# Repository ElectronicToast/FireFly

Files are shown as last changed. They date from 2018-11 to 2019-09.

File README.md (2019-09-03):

# FireFly

 

Open source ATmega8 target board with voltage regulation and ICSP, FTDI breakouts.

&nbsp;

FireFly

## Description

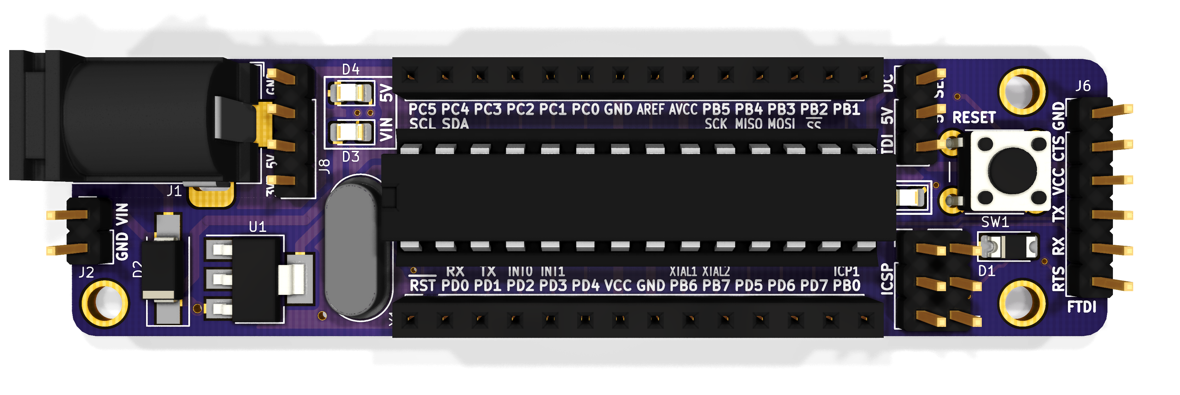
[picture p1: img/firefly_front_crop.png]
FireFly-Front


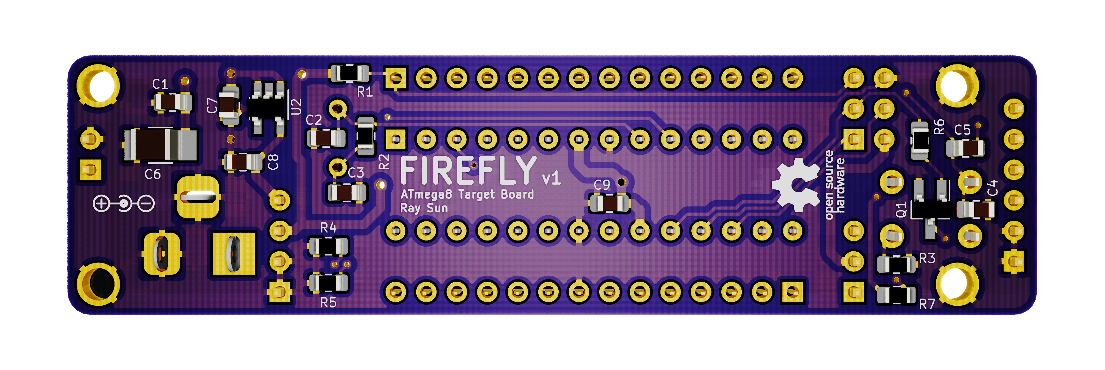
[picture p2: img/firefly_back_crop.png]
FireFly-Back


FIREFLY is an open-source ATmega8 (ATmega328) target board that might be likened to a lightweight yet accessible Arduino Uno R3. It is intended to be used for learning AVR C/C++ or AVR Assembly with Atmel Studio. A 16 MHz oscillator and reset circuit is provided for a complete microcontroller system. 5V and 3V3 power are created from DC input. The 28 pins of the ATmega8 DIP package are brought out onto breadboard-compatible headers so that the whole board may be plugged directly into a breadboard and used.

The ATmega8 may be programmed through the onboard ICSP or FTDI headers with an appropriate programmer. The power source for the target may be selected by a jumper shunt; when programming, take care not to power the target through the DC input (VIN) in addition to the programmer.

Designed with KiCad EDA 5.0.1. Gerber and drill files for fabrication may be found in `/gerber`, while documentation in pdf format may be found in `/pdf`. 

## Author
- Ray Sun - Undergraduate, Electrical Engineering, Caltech, Class of 2020

I created this board to help me enhance my knowledge of embedded systems development and working with AVRs.

## Licensing
<br />This work is licensed under a <a rel="license" href="http://creativecommons.org/licenses/by-sa/3.0/">Creative Commons Attribution-ShareAlike 3.0 Unported License</a>.

This design is a derivative of the [Arduino Uno Rev3](https://store.arduino.cc/usa/arduino-uno-rev3) board and is inspired by Adafruit Industries' [DC Boarduino](https://www.adafruit.com/product/72) by Limor Fried. Arduino is a trademark of Arduino AG. This design is not affiliated with Arduino AG.

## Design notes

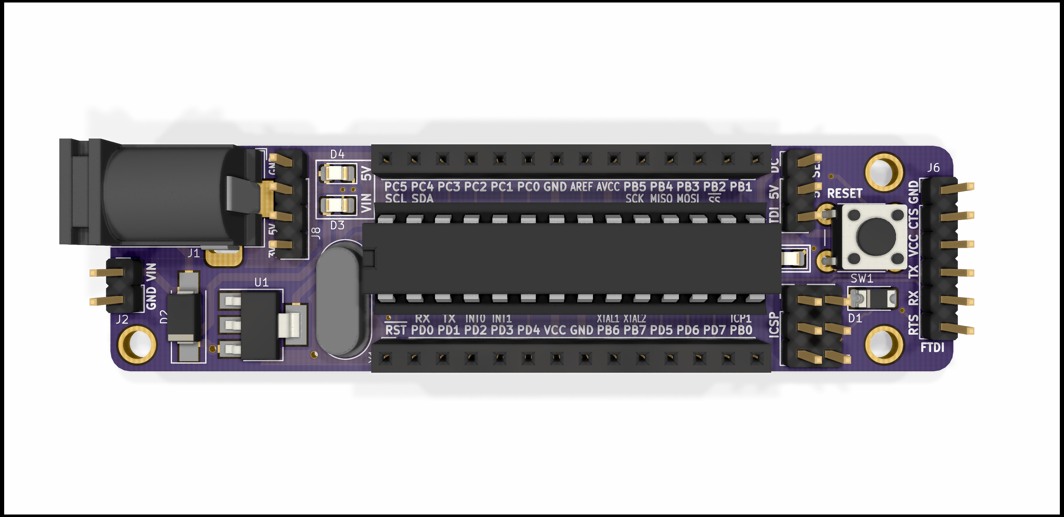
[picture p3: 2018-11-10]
img/firefly_front.png

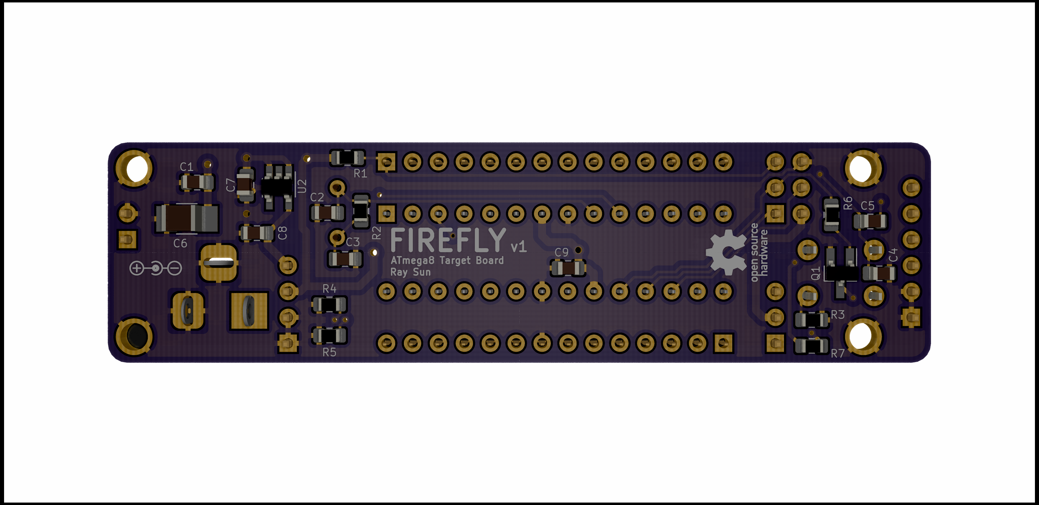
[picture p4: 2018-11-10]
img/firefly_back.png

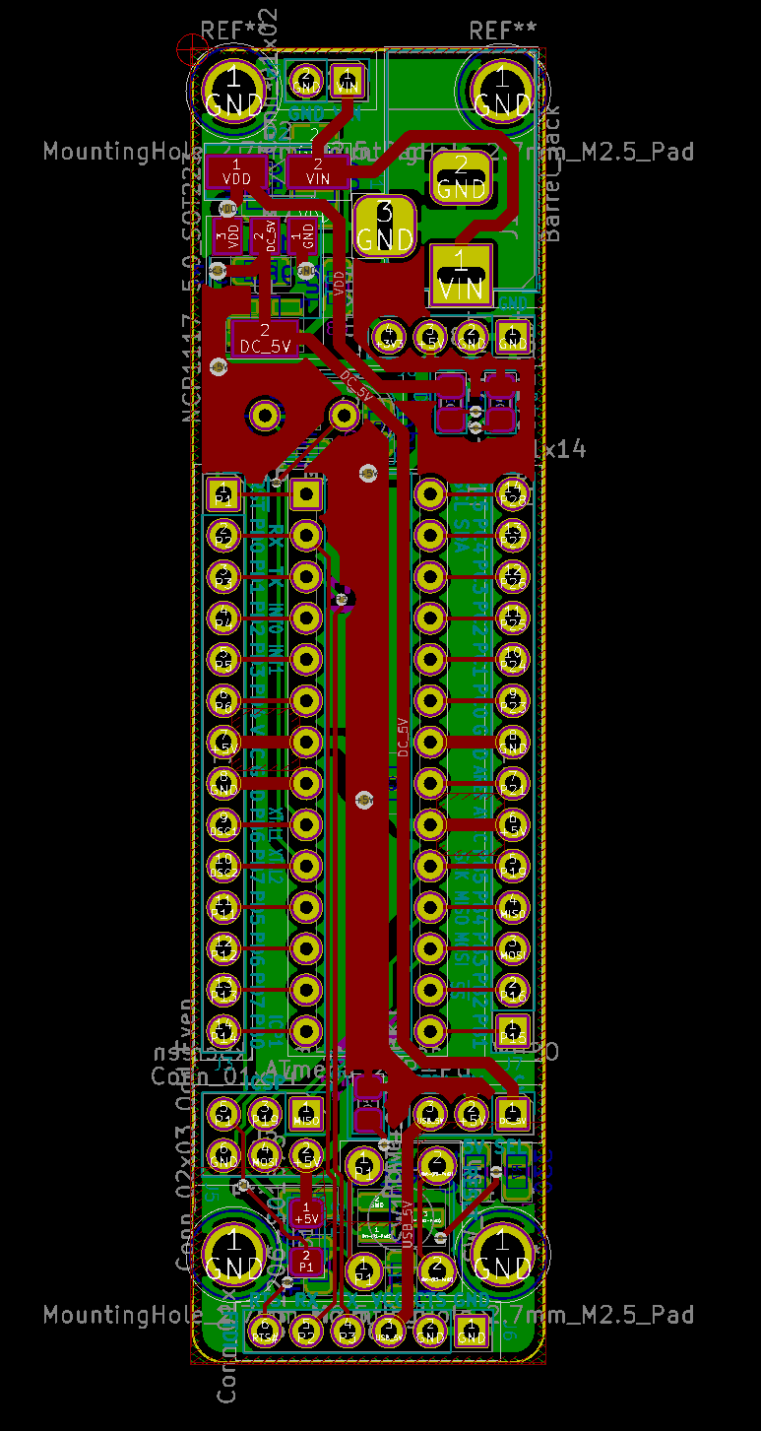
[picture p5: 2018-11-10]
img/firefly_layout.PNG

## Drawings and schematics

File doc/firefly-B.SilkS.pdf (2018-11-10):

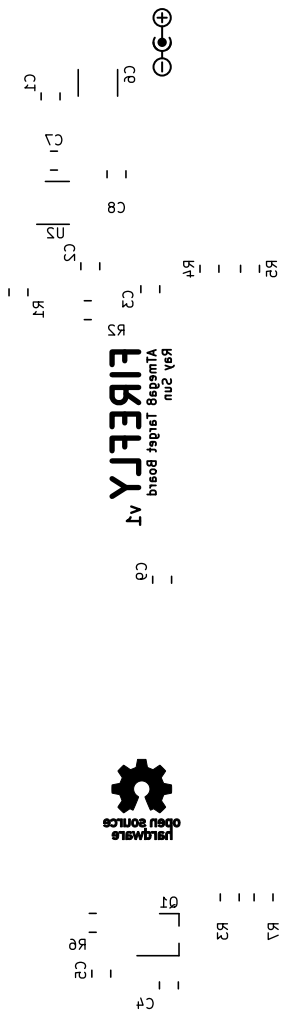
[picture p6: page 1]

v1 FIREFLY ATmega8 Target Board Ray Sun C9 C1 C7 C8 C2 C3 C5 C4 R2 R1 R4 R5 R3 R7 U2 C6 Q1 R6

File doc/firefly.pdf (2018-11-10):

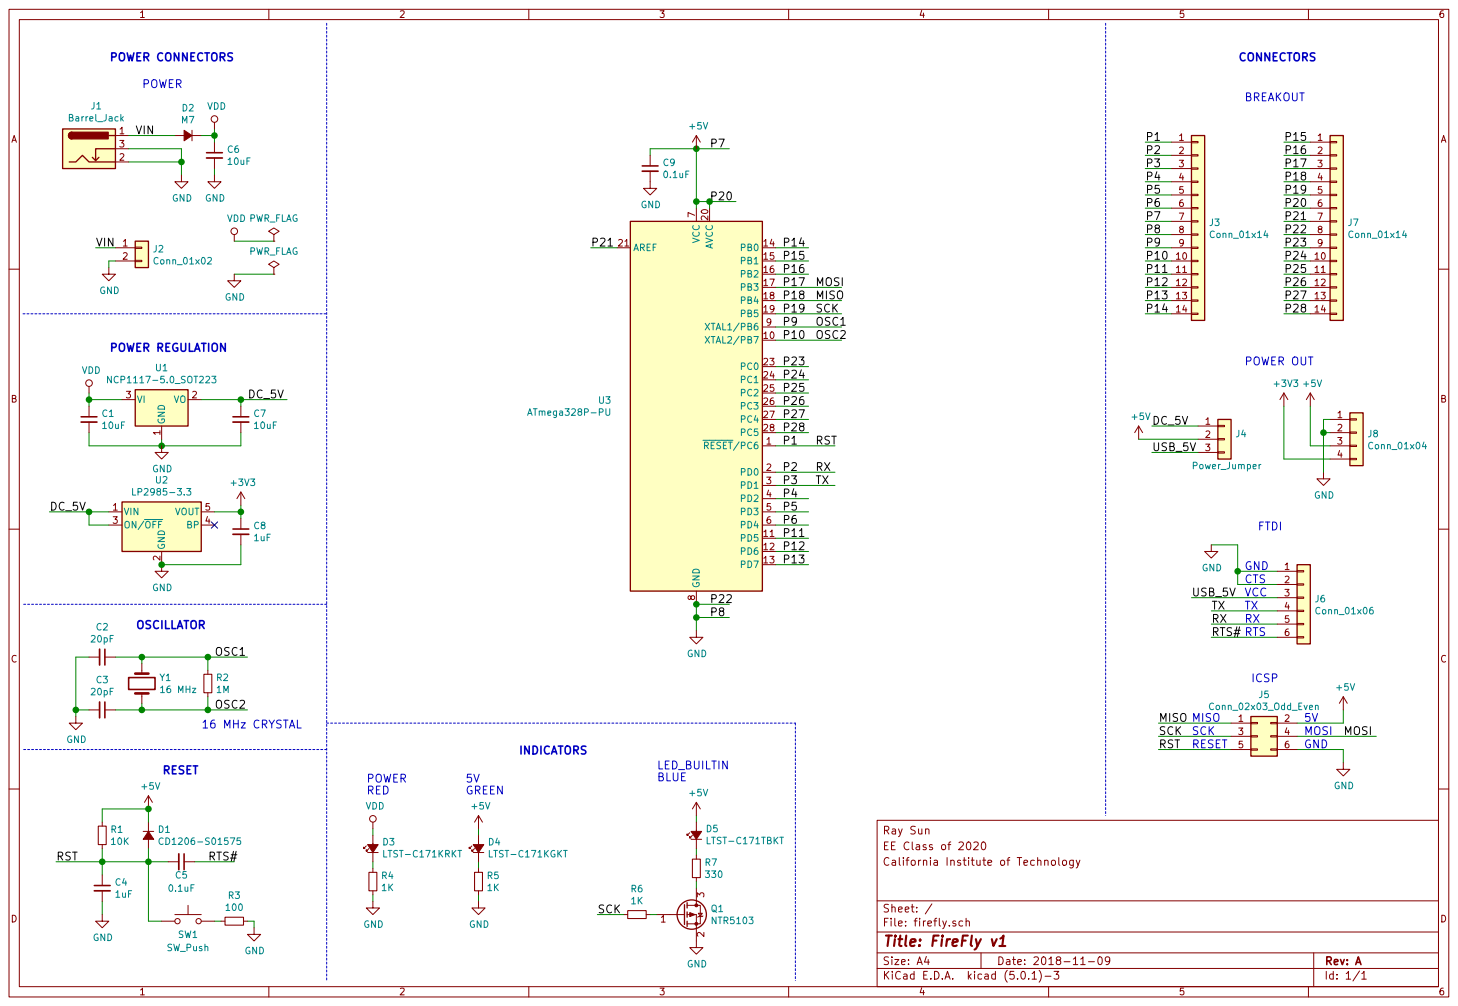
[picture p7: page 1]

1 VO 2 VI 3 U1 NCP1117-5.0_SOT223 VIN 1 GND
VDD

File: firefly.sch Sheet: / California Institute of Technology EE Class of 2020 Ray Sun

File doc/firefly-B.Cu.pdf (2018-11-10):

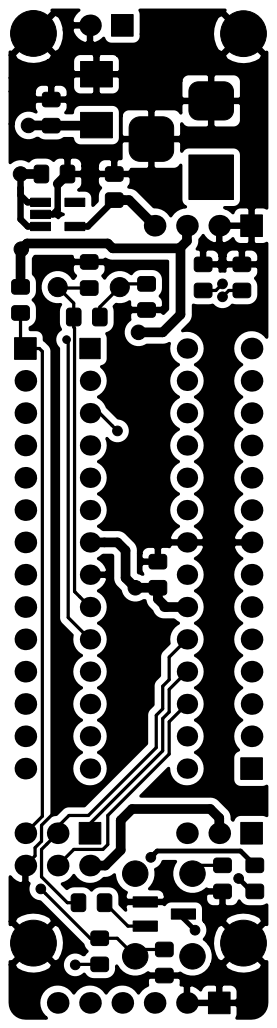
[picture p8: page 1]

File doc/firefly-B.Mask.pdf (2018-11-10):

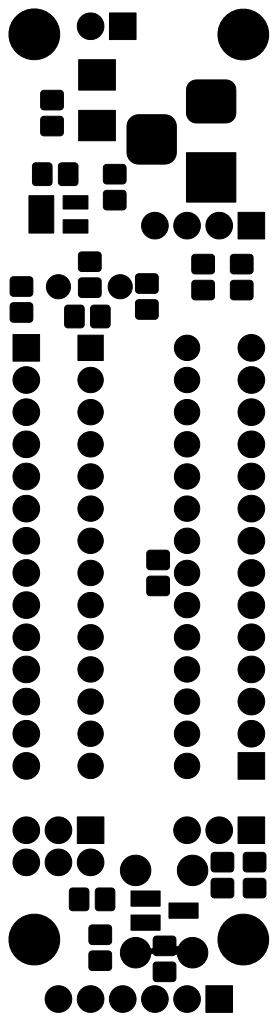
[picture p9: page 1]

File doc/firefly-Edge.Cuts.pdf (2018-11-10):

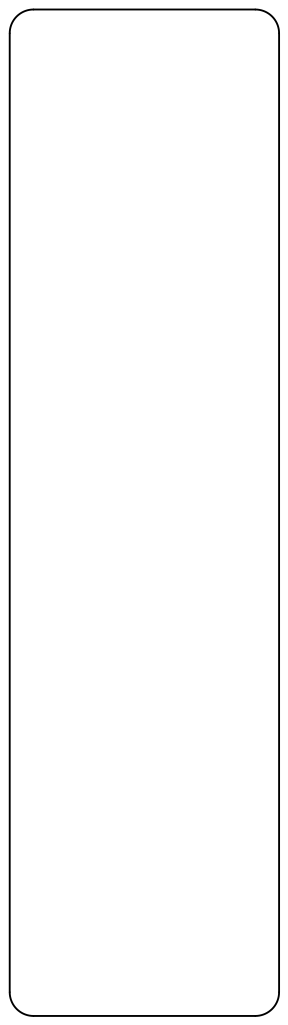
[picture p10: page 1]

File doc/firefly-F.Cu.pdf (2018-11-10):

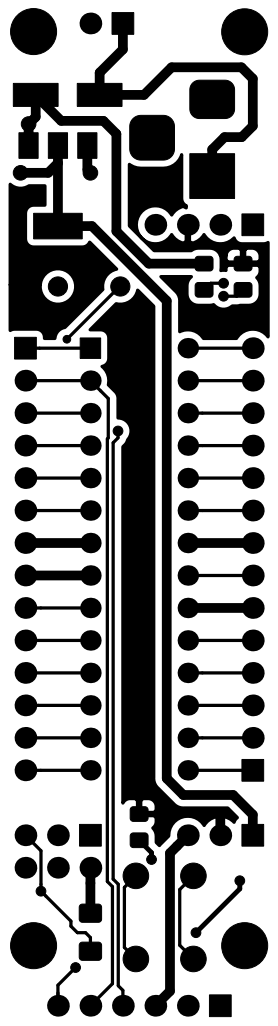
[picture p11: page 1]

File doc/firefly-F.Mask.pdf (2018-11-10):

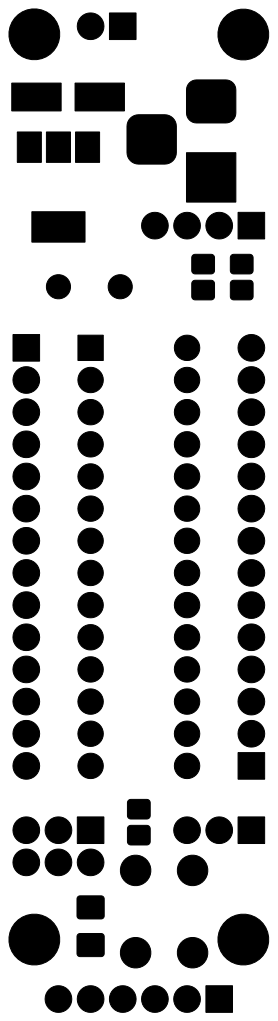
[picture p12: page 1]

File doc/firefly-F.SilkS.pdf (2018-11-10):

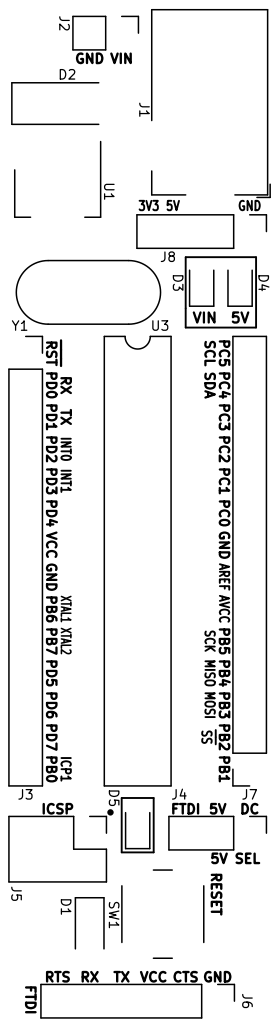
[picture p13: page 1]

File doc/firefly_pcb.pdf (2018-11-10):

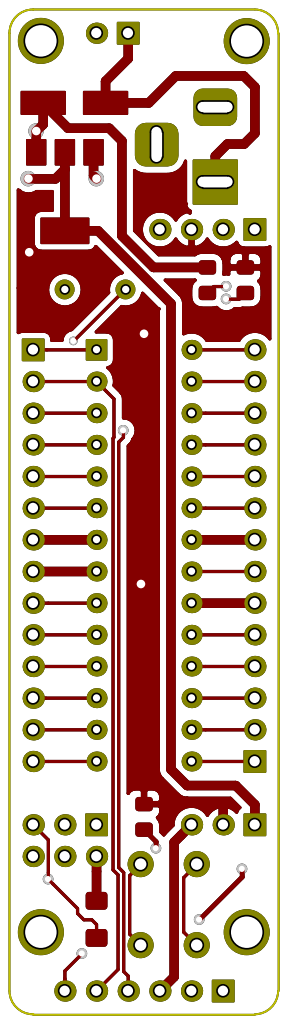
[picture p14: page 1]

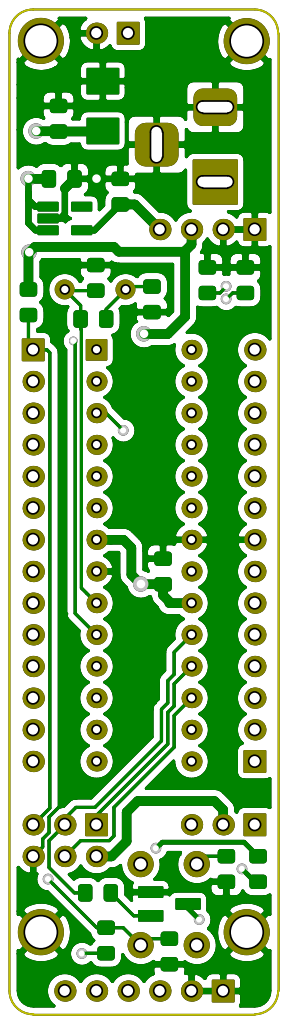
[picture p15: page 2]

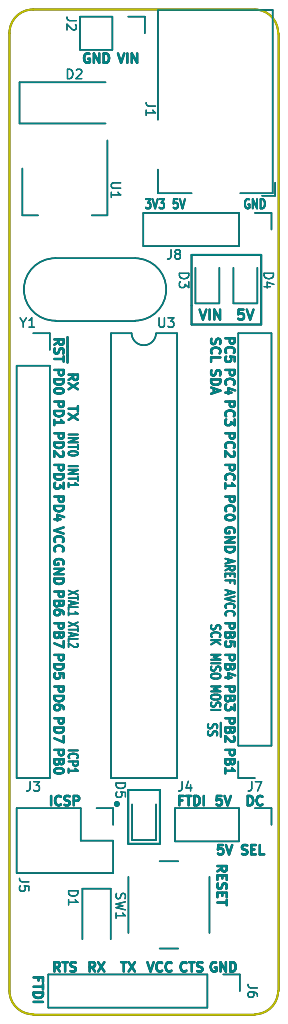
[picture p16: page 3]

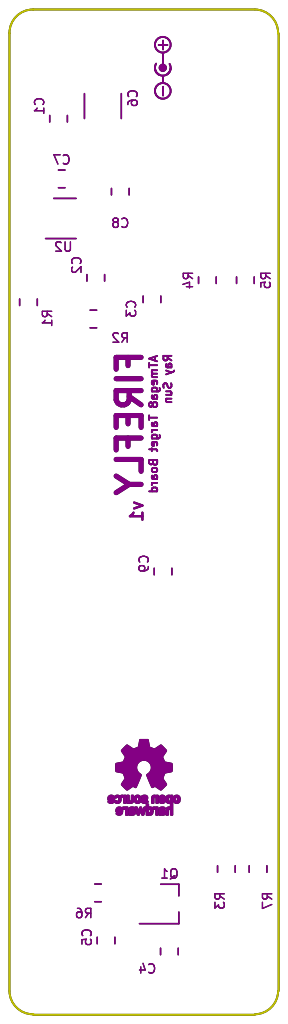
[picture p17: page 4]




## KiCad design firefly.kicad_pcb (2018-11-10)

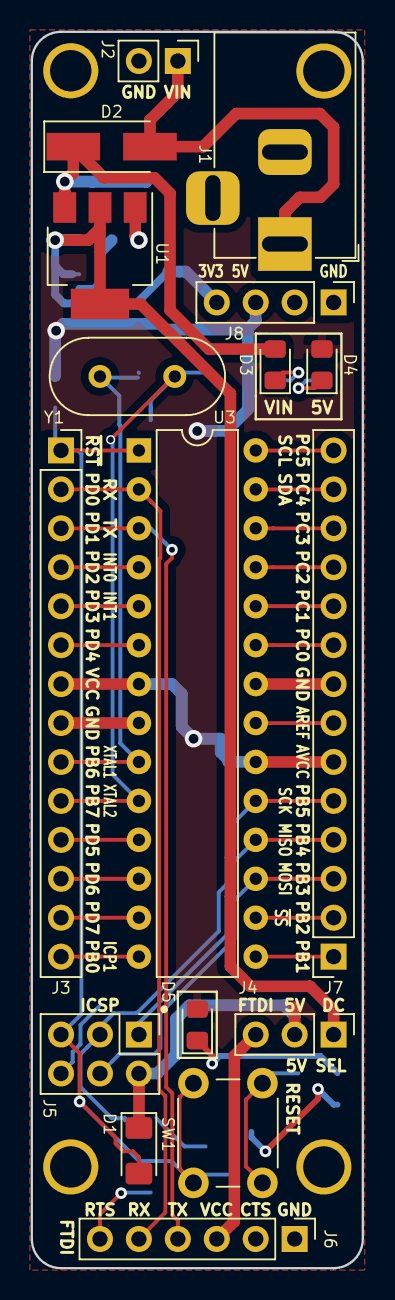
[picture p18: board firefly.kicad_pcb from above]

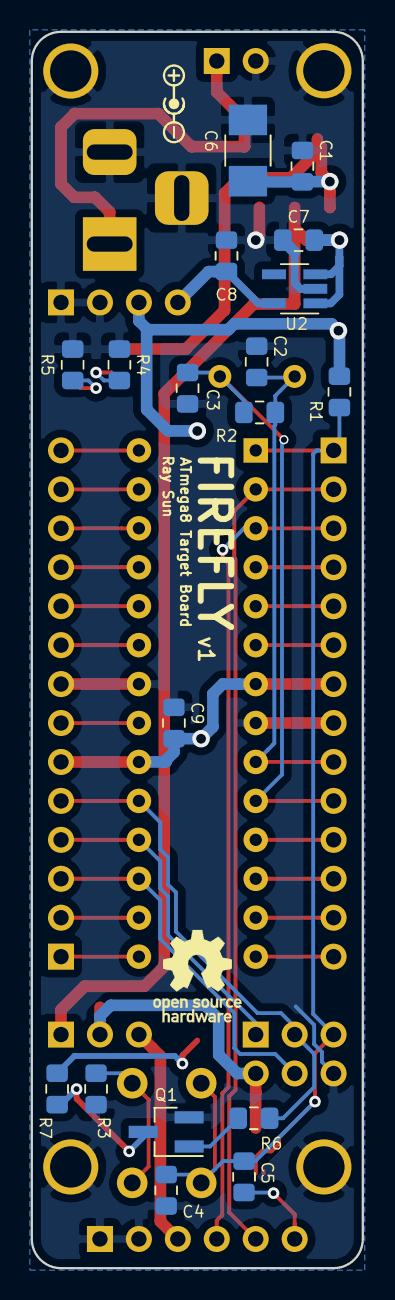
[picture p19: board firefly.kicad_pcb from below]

Board: 2 copper layers, 21.6 x 80.6 mm, 35 parts (18 on the bottom side), 38 nets.

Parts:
C1, C7: 10uF; C_0805_2012Metric_Pad1.15x1.40mm_HandSolder
C2, C3: 20pF; C_0805_2012Metric_Pad1.15x1.40mm_HandSolder
C4, C8: 1uF; C_0805_2012Metric_Pad1.15x1.40mm_HandSolder
C5, C9: 0.1uF; C_0805_2012Metric_Pad1.15x1.40mm_HandSolder
C6: 10uF; C_1210_HandSoldering
D1: CD1206-S01575; D_1206_3216Metric_Pad1.42x1.75mm_HandSolder
D2: M7; D_SMA_Handsoldering
D3: LTST-C171KRKT; LED_0805_2012Metric_Pad1.15x1.40mm_HandSolder
D4: LTST-C171KGKT; LED_0805_2012Metric_Pad1.15x1.40mm_HandSolder
D5: LTST-C171TBKT; LED_0805_2012Metric_Pad1.15x1.40mm_HandSolder
J1: Barrel_Jack; BarrelJack_Horizontal
J2: Conn_01x02; PinHeader_1x02_P2.54mm_Vertical
J3, J7: Conn_01x14; PinSocket_1x14_P2.54mm_Vertical
J4: Power_Jumper; PinHeader_1x03_P2.54mm_Vertical
J5: Conn_02x03_Odd_Even; PinHeader_2x03_P2.54mm_Vertical
J6: Conn_01x06; PinHeader_1x06_P2.54mm_Vertical
J8: Conn_01x04; PinHeader_1x04_P2.54mm_Vertical
Q1: NTR5103; SOT-23_Handsoldering
R1: 10K; R_0805_2012Metric_Pad1.15x1.40mm_HandSolder
R2: 1M; R_0805_2012Metric_Pad1.15x1.40mm_HandSolder
R3: 100; R_0805_2012Metric_Pad1.15x1.40mm_HandSolder
R4, R5, R6: 1K; R_0805_2012Metric_Pad1.15x1.40mm_HandSolder
R7: 330; R_0805_2012Metric_Pad1.15x1.40mm_HandSolder
SW1: SW_Push; SW_PUSH_6mm
U1: NCP1117-5.0_SOT223; SOT-223-3_TabPin2
U2: LP2985-3.3; SOT-23-5_HandSoldering
U3: ATmega328P-PU; DIP-28_W7.62mm
Y1: 16 MHz; Crystal_HC49-4H_Vertical

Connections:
+3V3: C8.1, J8.4, U2.5
+5V: C9.1, D1.1, D4.2, D5.2, J3.7, J4.2, J5.2, J7.6, J8.3, R1.1, U3.7, U3.20
/DC_5V: C7.1, J4.1, U1.2, U2.1, U2.3
/MISO: J5.1, J7.4, U3.18
/MOSI: J5.4, J7.3, U3.17
/OSC1: C2.1, J3.9, R2.1, U3.9, Y1.1
/OSC2: C3.1, J3.10, R2.2, U3.10, Y1.2
/P1: C4.1, C5.2, D1.2, J3.1, J5.5, R1.2, SW1.1, U3.1
/P2: J3.2, J6.5, U3.2
/P3: J3.3, J6.4, U3.3
/P4: J3.4, U3.4
/P5: J3.5, U3.5
/P6: J3.6, U3.6
/P11: J3.11, U3.11
/P12: J3.12, U3.12
/P13: J3.13, U3.13
/P14: J3.14, U3.14
/P15: J7.1, U3.15
/P16: J7.2, U3.16
/P19: J5.3, J7.5, R6.2, U3.19
/P21: J7.7, U3.21
/P23: J7.9, U3.23
/P24: J7.10, U3.24
/P25: J7.11, U3.25
/P26: J7.12, U3.26
/P27: J7.13, U3.27
/P28: J7.14, U3.28
/RTS#: C5.1, J6.6
/USB_5V: J4.3, J6.3
/VIN: D2.2, J1.1, J2.1
GND: C1.2, C2.2, C3.2, C4.2, C6.2, C7.2, C8.2, C9.2, J1.2, J1.3, J2.2, J3.8, J5.6, J6.1, J6.2, J7.8, J8.1, J8.2, Q1.2, R3.1, R4.2, R5.2, U1.1, U2.2, U3.8, U3.22
unnamed: D3.1, R4.1
unnamed: D4.1, R5.1
unnamed: D5.1, R7.1
unnamed: Q1.1, R6.1
unnamed: Q1.3, R7.2
unnamed: R3.2, SW1.2
VDD: C1.1, C6.1, D2.1, D3.2, U1.3

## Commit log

2018-09-26 Added files.
    [firefly-B.Cu.gbr, firefly-B.Mask.gbr, firefly-B.SilkS.gbr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]
2018-09-30 Moved some components and silkscreen around, replaced crystal.
    [firefly.kicad_pcb, firefly.sch]
2018-11-10 Add files for v1 release
    [firefly-B.Cu.gbl, firefly-B.Mask.gbs, firefly-B.SilkS.gbo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]
2018-11-10 Remove old Gerbers and add zip
    [firefly-B.Cu.gbr, firefly-B.Mask.gbr, firefly-B.SilkS.gbr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]
2018-12-24 Add physical board image
